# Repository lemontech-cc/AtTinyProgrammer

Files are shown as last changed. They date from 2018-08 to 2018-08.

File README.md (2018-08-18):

# AtTinyPtogrammer

AtTiny Programmer is not a simple shield for arduino one but it is a complete PCB that uses a Pro Micro card to directly program the AtTiny family processors.

You can program Attiny84 and Attiny85 with a simple USB cable and the Arduino IDE.
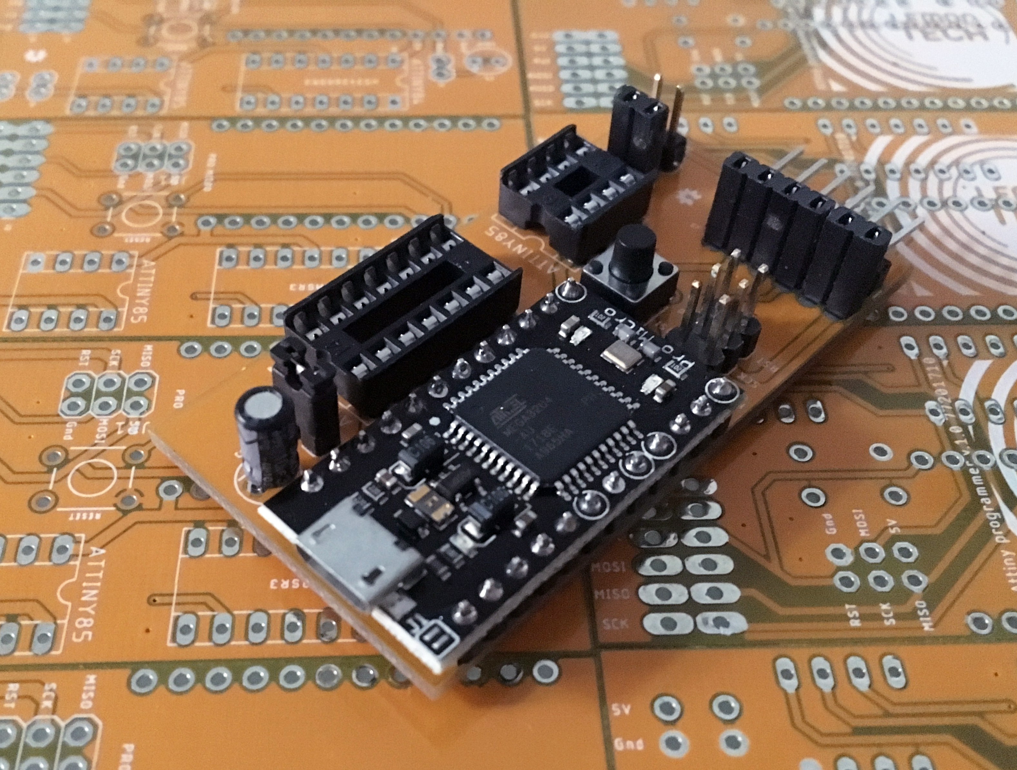
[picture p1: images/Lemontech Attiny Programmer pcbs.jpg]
Lemontech AtTiny Prommare & PCBs


### Instruction of Use:

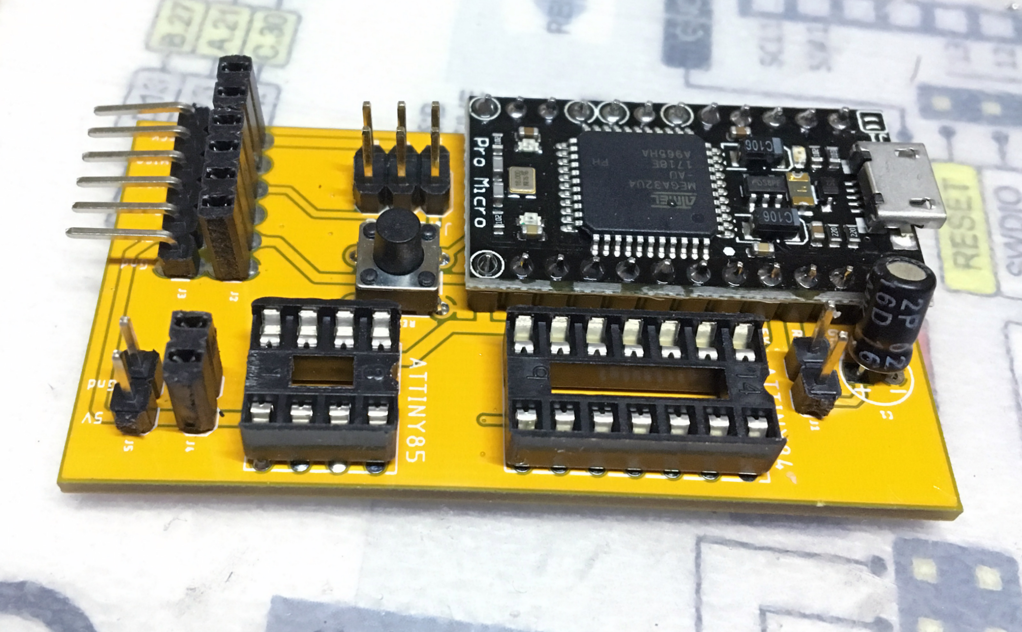
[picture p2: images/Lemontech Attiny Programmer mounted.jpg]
Lemontech AtTiny Programmer


Use the Dip8 socket to Proram [AtTiny85](https://www.microchip.com/wwwproducts/en/ATtiny85) and each other processors with this socket of AVR Attiny family:

* AtTiny25
* AtTiny45
* AtTiny85

Use the Dip14 socket to Proram [AtTiny84](https://www.microchip.com/wwwproducts/en/ATtiny84) and each other processors with this socket of AVR Attiny family:

* AtTiny24
* AtTiny44
* AtTiny84

### To pre-programming the Pro Micro

** Step 1 **

Remove the jumper J1 and select on the Arduino IDE the sketch 
*Examples -> 11. ArduinoISO -> ArduinoISP*

Select the board: *Arduino Pro or Pro Mini*

Upload the sketch on the Pro Micro ...

** Step 2 **
Reconnect the jumper J1 and select in the Arduino IDE the Attiny processor family, es: Attiny85;

In teh Tools menu select:

*Programmer: Arduino as ISP*

** Step 3 **

Select your sketch for Attiny85 and Upload it.

More Info: [lemontech.cc](http://www.lemontech.cc)

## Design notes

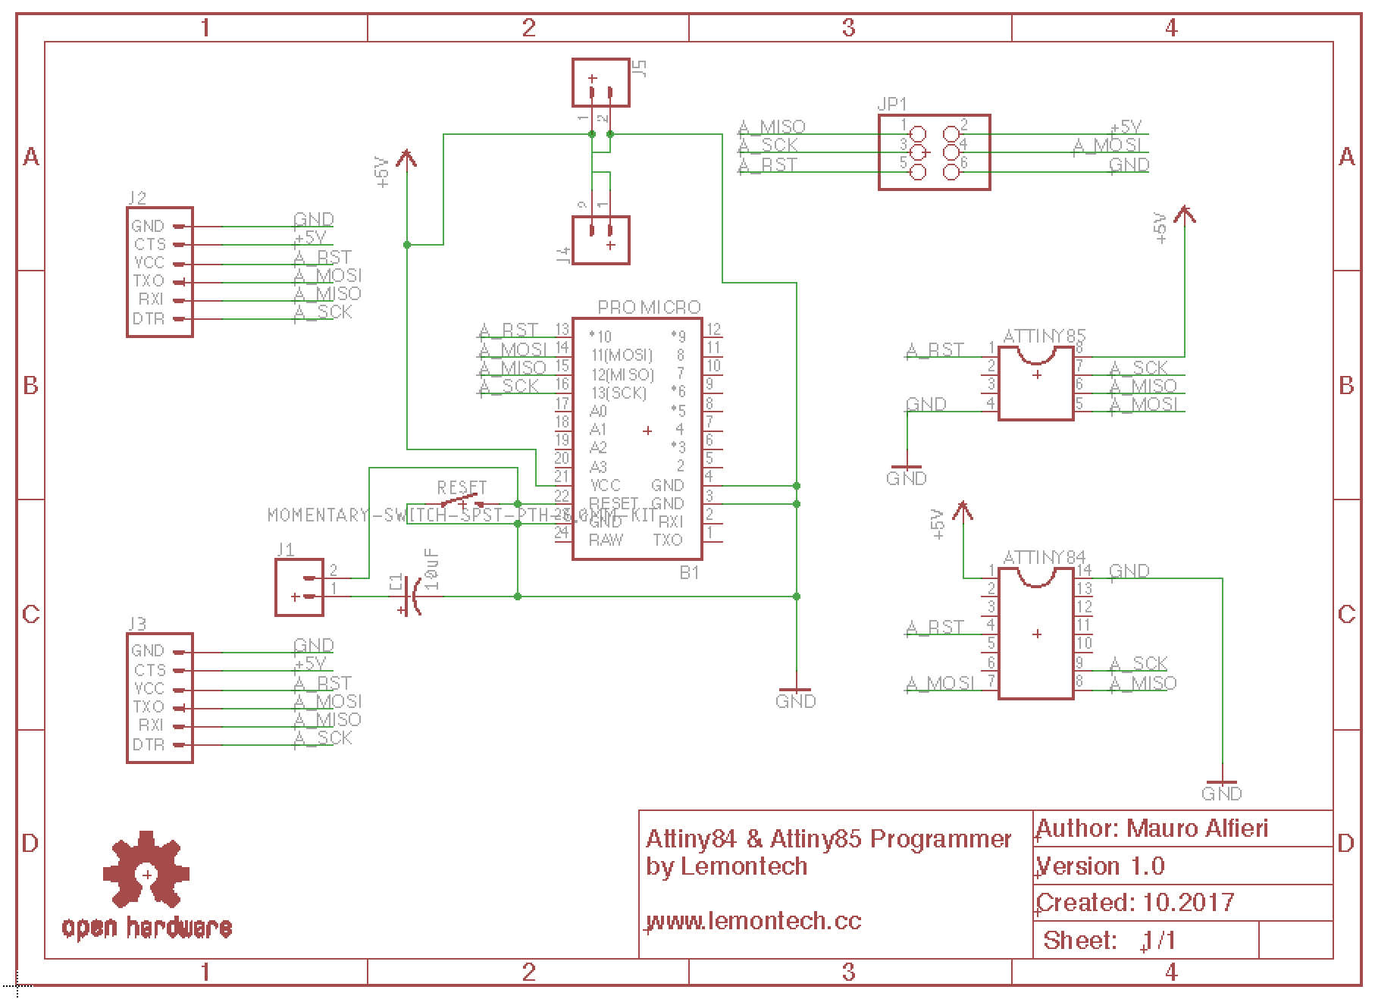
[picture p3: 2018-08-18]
images/Lemontech Attiny Programmer schematic.png

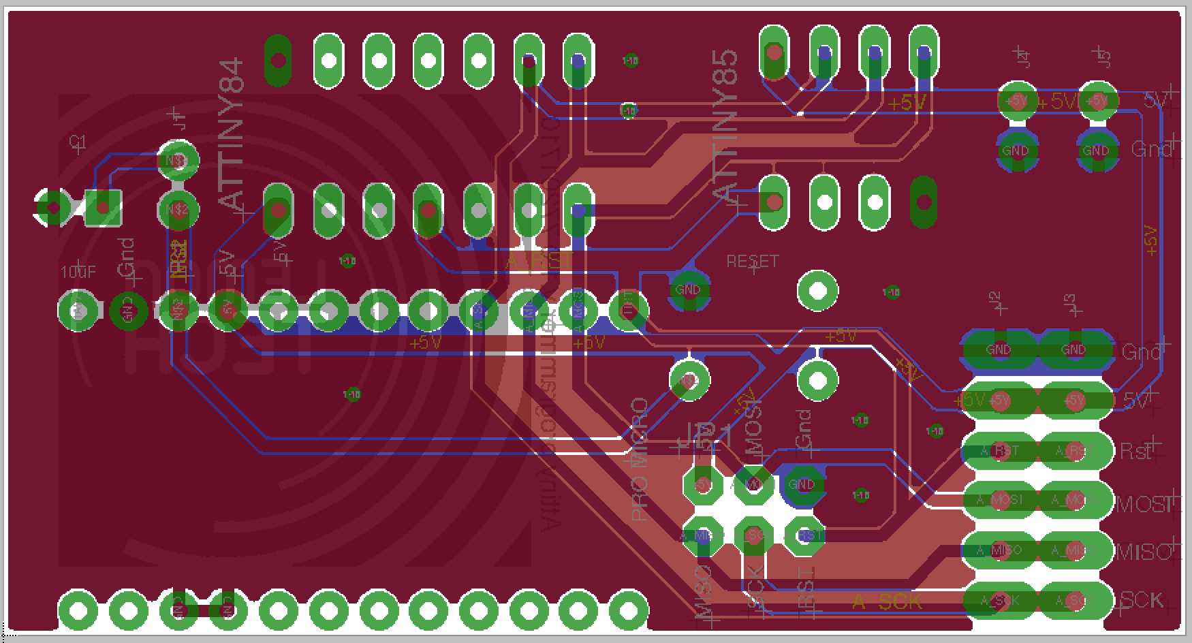
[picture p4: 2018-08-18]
images/Lemontech Attiny Programmer board.png

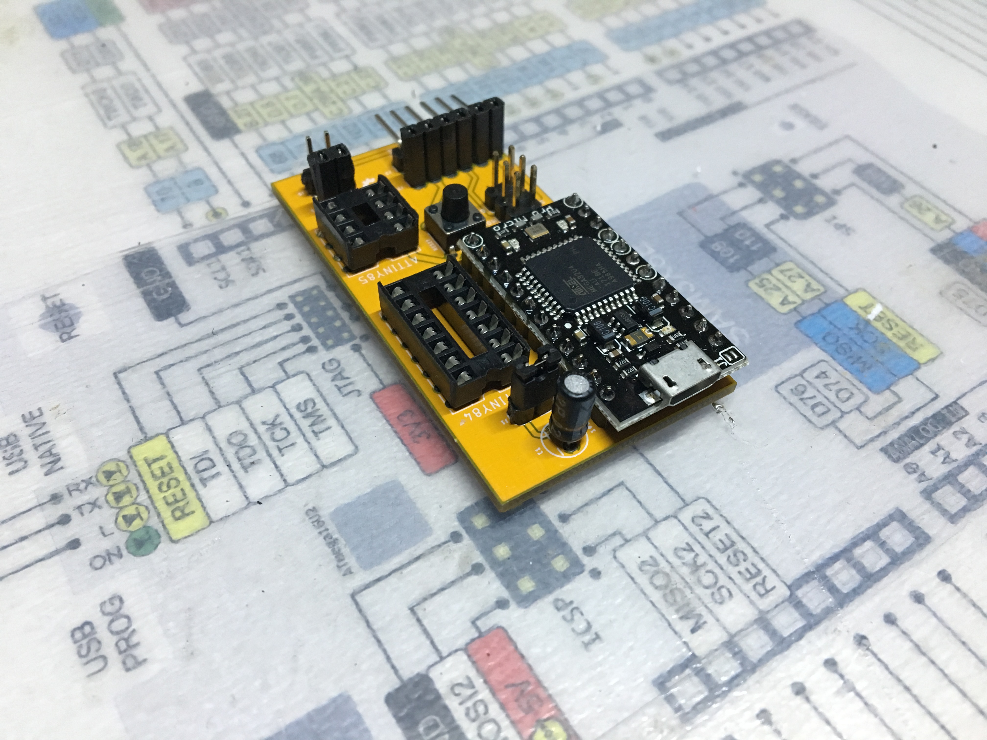
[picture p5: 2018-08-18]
images/Lemontech Attiny Programmer.jpg

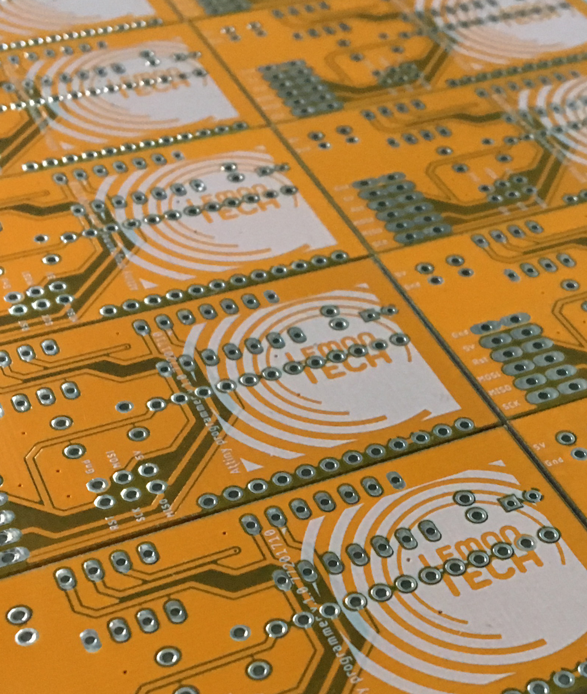
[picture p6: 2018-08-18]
images/Lemontech Attiny Programmer PCBs new II.jpg

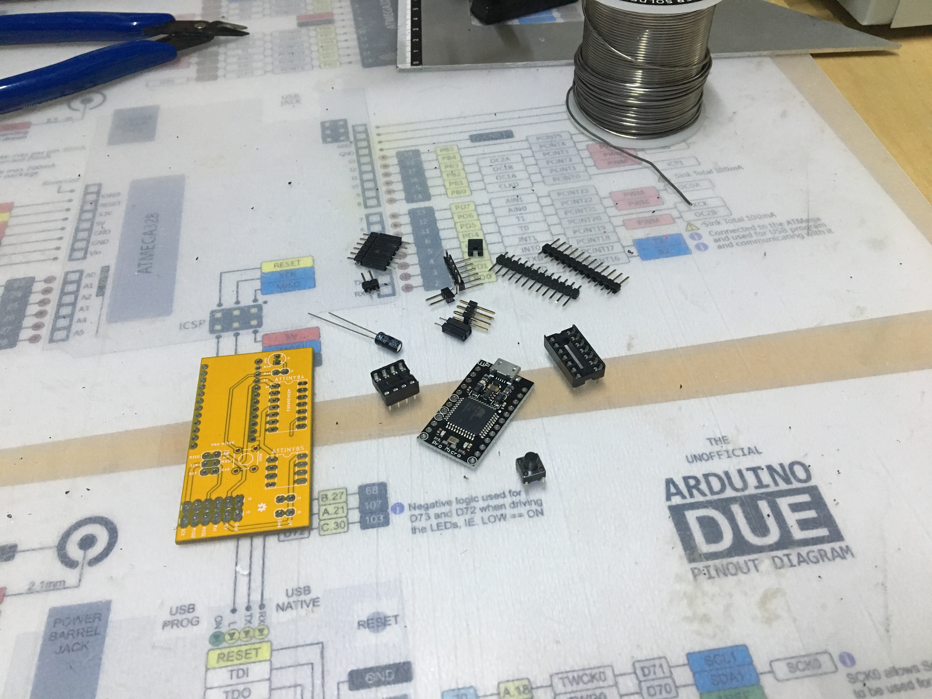
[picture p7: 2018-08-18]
images/Lemontech Attiny Programmer staring mount.jpg

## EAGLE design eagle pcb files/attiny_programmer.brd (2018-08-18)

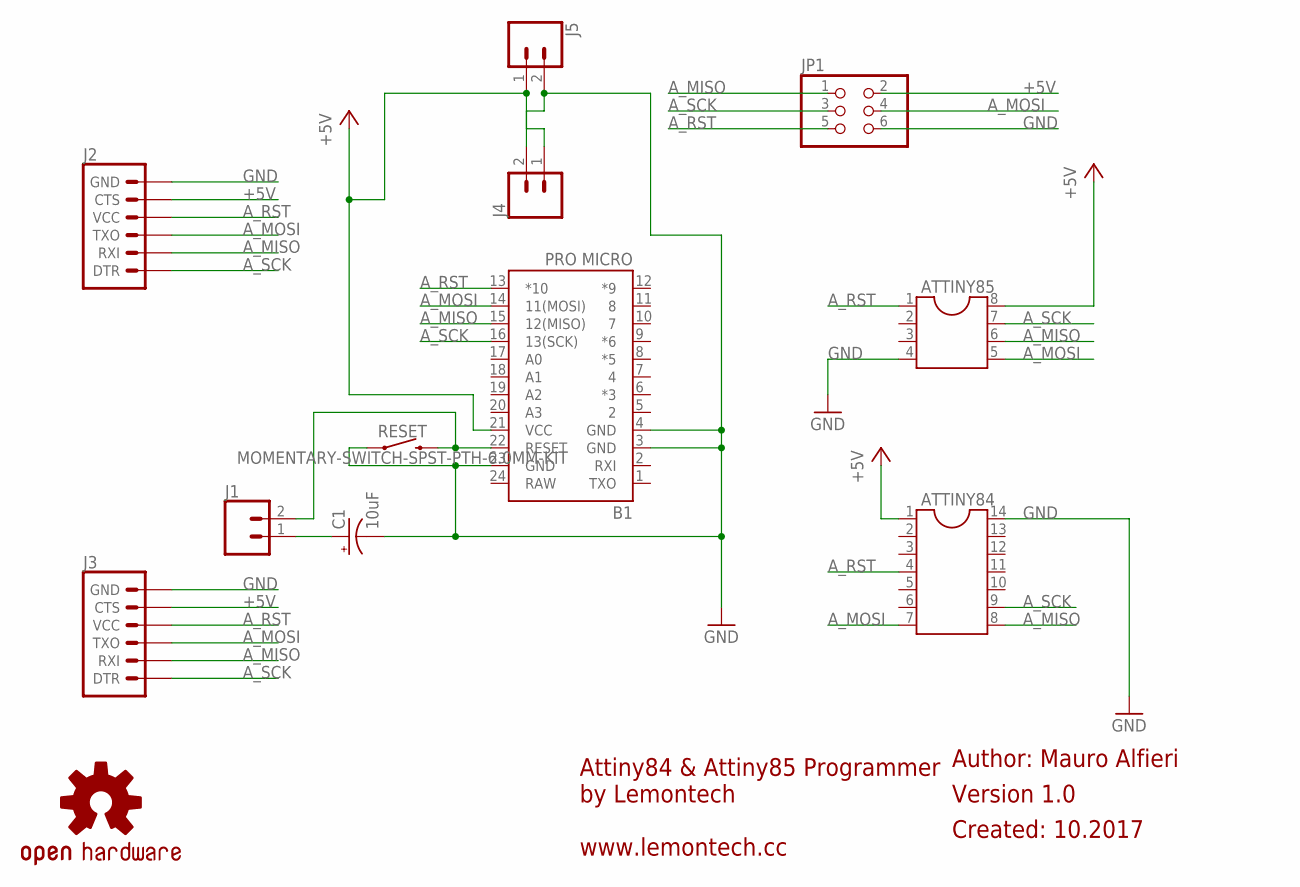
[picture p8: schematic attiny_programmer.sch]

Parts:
ATTINY84: DIL14S; SOCKET-14
ATTINY85: DIL8S; SOCKET-08
B1: PRO MICRO; SPARKFUN_PRO_MICRO
C1: 10uF; CPOL-RADIAL-2.5MM-5MM
J1, J4, J5: CONN_02; 1X02
J2, J3: 6_PIN_SERIAL_TARGETLONGPADS; 1X06_LONGPADS
JP1: PINHD-2X3; 2X03
LOGO1: OSHW-LOGOMINI; OSHW-LOGO-MINI
RESET: MOMENTARY-SWITCH-SPST-PTH-6.0MM-KIT; TACTILE_SWITCH_PTH_6.0MM_KIT

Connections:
+5V: ATTINY84.1, ATTINY85.8, B1.21 (VCC), J2.5 (CTS), J3.5 (CTS), J4.1, J5.1, JP1.2
A_MISO: ATTINY84.8, ATTINY85.6, B1.15 (12(MISO)), J2.2 (RXI), J3.2 (RXI), JP1.1
A_MOSI: ATTINY84.7, ATTINY85.5, B1.14 (11(MOSI)), J2.3 (TXO), J3.3 (TXO), JP1.4
A_RST: ATTINY84.4, ATTINY85.1, B1.13 (*10), J2.4 (VCC), J3.4 (VCC), JP1.5
A_SCK: ATTINY84.9, ATTINY85.7, B1.16 (13(SCK)), J2.1 (DTR), J3.1 (DTR), JP1.3
GND: ATTINY84.14, ATTINY85.4, B1.3 (GND), B1.4 (GND), B1.23 (GND), C1.2 (-), J2.6 (GND), J3.6 (GND), J4.2, J5.2, JP1.6, RESET.1
unnamed: B1.22 (RESET), J1.2, RESET.3 (2)
unnamed: C1.1 (+), J1.1
RAW: B1.24 (RAW)

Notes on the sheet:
Attiny84 & Attiny85 Programmer by Lemontech www.lemontech.cc
Version 1.0
Author: Mauro Alfieri
Created: 10.2017

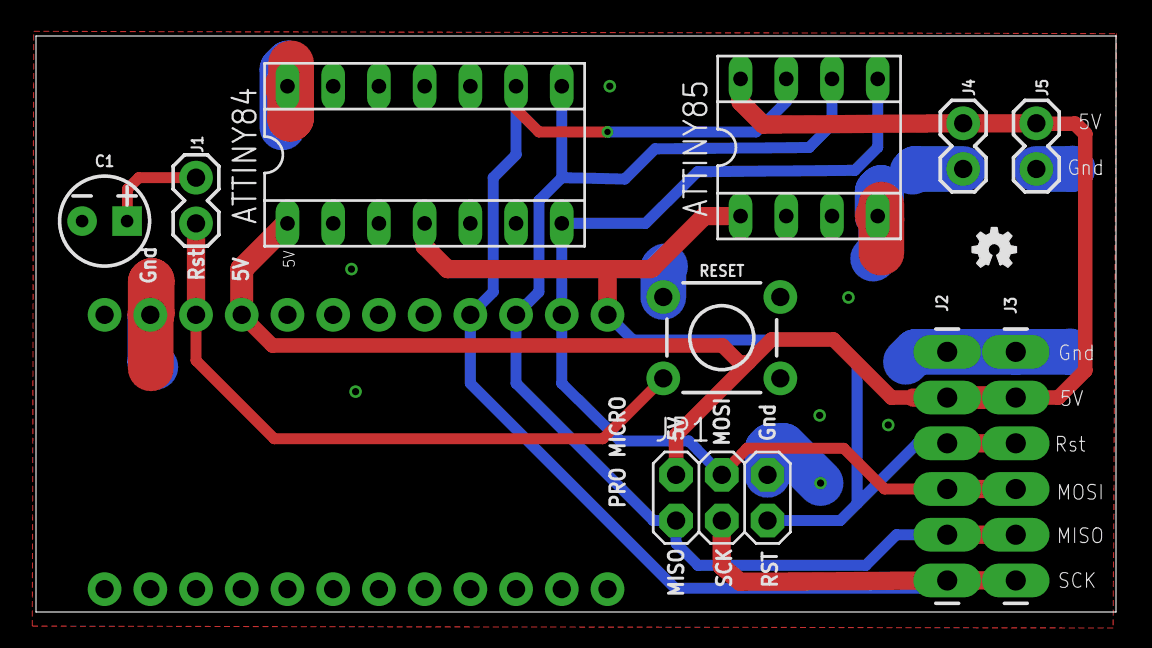
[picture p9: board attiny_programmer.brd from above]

Board: 2 copper layers, 60.0 x 32.0 mm, 13 parts (1 on the bottom side), 8 nets.

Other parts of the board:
U$1: LOGO_1MIL

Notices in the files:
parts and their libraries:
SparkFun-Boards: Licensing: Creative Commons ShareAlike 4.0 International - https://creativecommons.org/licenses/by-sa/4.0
